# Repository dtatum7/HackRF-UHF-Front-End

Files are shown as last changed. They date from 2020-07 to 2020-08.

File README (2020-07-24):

Copyright 2020 Daniel H. Tatum

This source describes Open Hardware and is licensed under the CERN-OHL-P v2
You may redistribute and modify this documentation and make products
using it under the terms of the CERN-OHL-P v2 (https:/cern.ch/cern-ohl).
This documentation is distributed WITHOUT ANY EXPRESS OR IMPLIED
WARRANTY, INCLUDING OF MERCHANTABILITY, SATISFACTORY QUALITY
AND FITNESS FOR A PARTICULAR PURPOSE. Please see the CERN-OHL-P v2
for applicable conditions

https://github.com/dtatum7/HackRF-UHF-Front-End/blob/master/PCB_View.png

This project includes design and manufacturing files to produce a 400MHz to
500MHz UHF front end suitable for radio communications at distances of 5
miles or greater on a tuned omnidirectional antenna (as is used on a HAM
mobile rig, handy-talkie, or base station).

The project is in its infancy. HackRF UHF Front End is an evaluation and
prototyping platform to develop a half-duplex LNA and PA chain for the
HackRF at UHF frequencies covering HAM, commercial, GMRS, and other bands.
The design and layout files contain additional artwork to probe the RF
matching networks during testing. All power and control nets will be
externally controlled in the initial version. Futurerevisions will have
power supplies and control circuitry integrated onto the PCBA.

hardware notes:

Schematic, layout, and PCB manufacturing files were designed in KiCad, an open source electronic
design automation package. Simulations have been performed using LibreOffice
Spreadsheets and Qucs simulations as referenced in Documentation.

order of copper layers:
    Copper 1:  C1F (front)
    Copper 2:  C2
    Copper 3:  C3
    Copper 4:  C4B (back)

PCB description: 4 layer PCB 0.062 in
    Copper        1   0.5 oz foil plated to approximately 0.0017 in
    Dielectric  1-2   0.0119 in
    Copper        2   1 oz foil (0.0014 in)
    Dielectric  2-3   0.0280 in
    Copper        3   1 oz foil (0.0014 in)
    Dielectric  3-4   0.0119 in
    Copper        4   0.5 oz foil plated to approximately 0.0017 in

FR4 or similar substrate with Er=4.5 (+/- 0.1)
double side solder mask green
single side silkscreen white
6 mil min trace width and
6 mil min isolation

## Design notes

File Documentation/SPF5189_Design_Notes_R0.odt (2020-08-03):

SPF5189Z Design Notes

Daniel H. Tatum

Revision 0

08/02/20

# Introduction

The Qorvo SPF5189Z [1] meets frequency and gain requirements while delivering excellent linearity with an OIP3 of 39.5dBm. The output power of +22.5dBm at the 1dB compression point makes the amplifier an ideal driver for a 4W-8W power amplifier.Integration requires a +5V power supply at 90mA of current, band-limiting matching networks, and DC blocking capacitors at both the input and output terminals. The SOT-89-3 package is simple to install in a home lab with a board heater and quality soldering iron.

# Matching Network Design

Discrete matching networks are designed in the Quite Universal Circuit Simulator using manufacturer provided scattering parameter data and built-in microstrip models.

## Stability Circles

A check of the Rollett stability factor indicates that a stable match on both the input (red) and output (blue) networks can be made anywhere on the Smith Chart as in Figure 1.

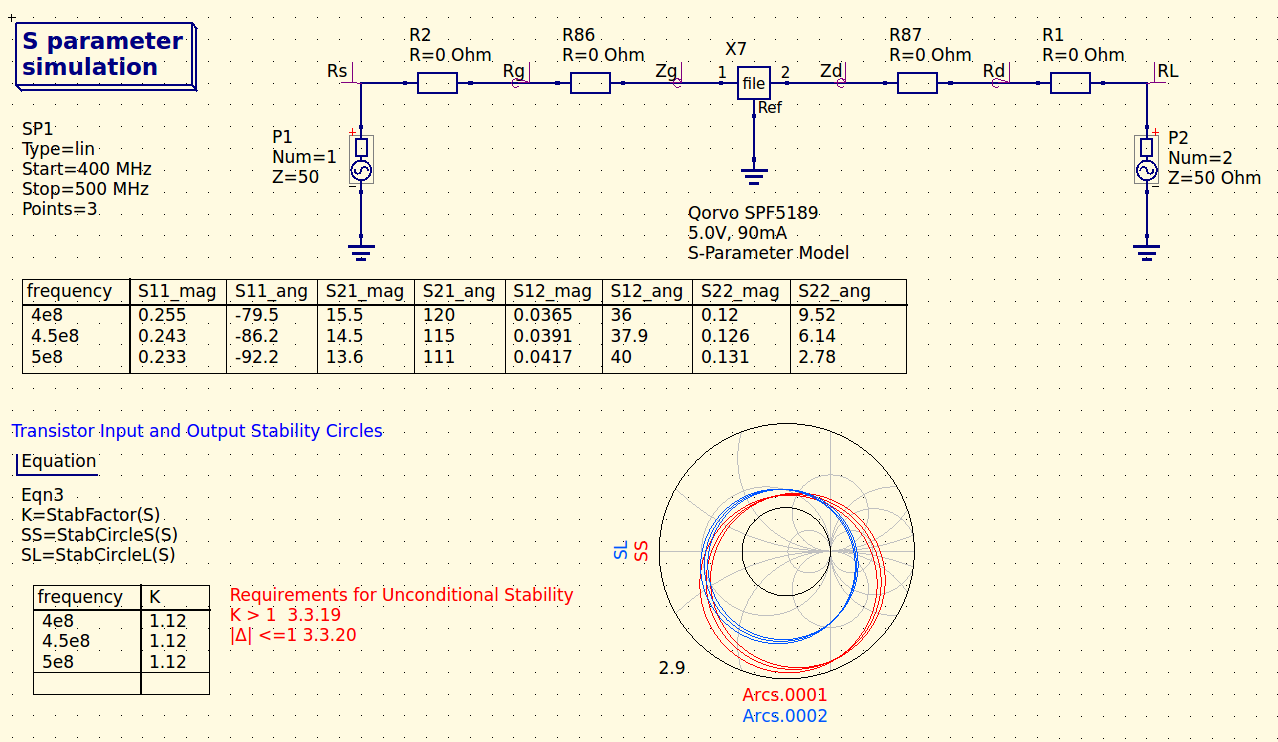
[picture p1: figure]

Figure 1. Qucs Simulation deck for Rollett stability factor.

## Input Network

A simulation has been configured in Qucs to automate the calculation of the required simultaneous conjugate matching coefficients to achieve maximum power output from the amplifier. The design process has been borrowed from [2] with the resulting coefficients in Figure 2.

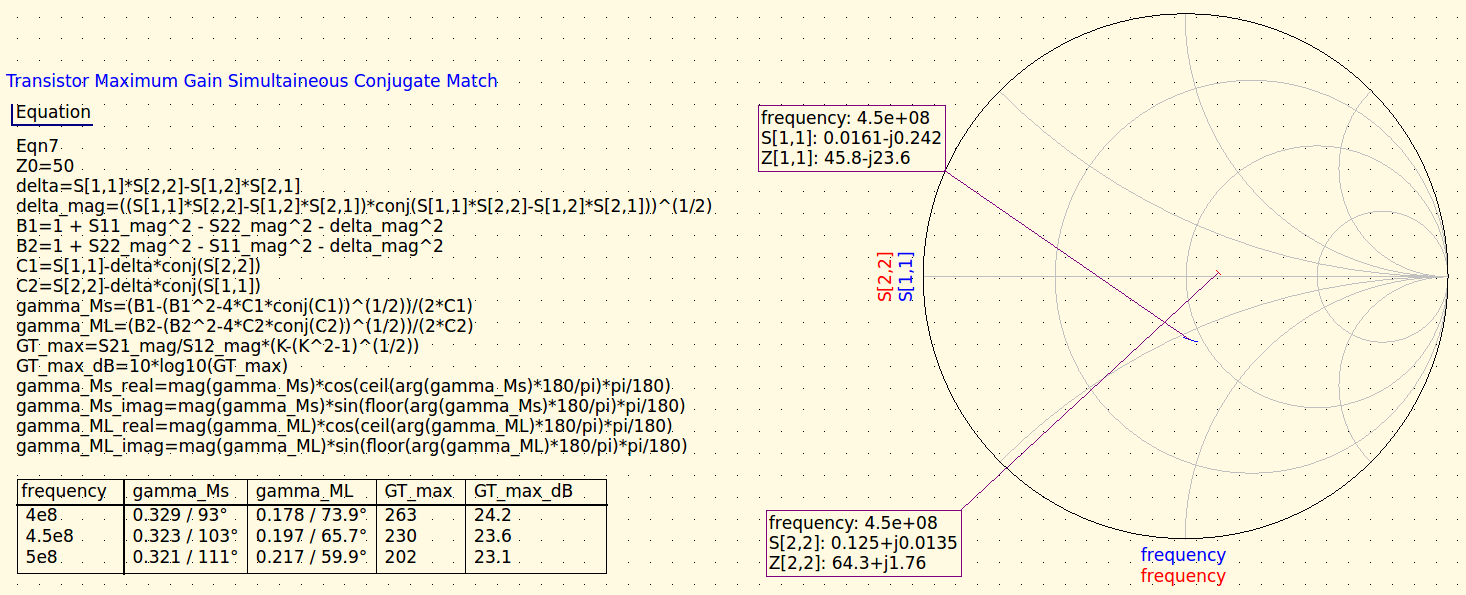
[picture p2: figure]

Figure 2. Simultaneous conjugate matching reflection coefficients for the source (gamma_Ms) and load (gamma_ML) ports calculated using S-parameter data. The input reflection coefficient, S[1,1] (blue), and output reflection coefficient, S[2,2] (red), presented on the Smith chart represent the the reflection coefficients seen by the ports with characteristic impedance of 50Ω.

The required input impedance is then calculated and presented rectangular form in Figure 2 to subsequently determine required component values.

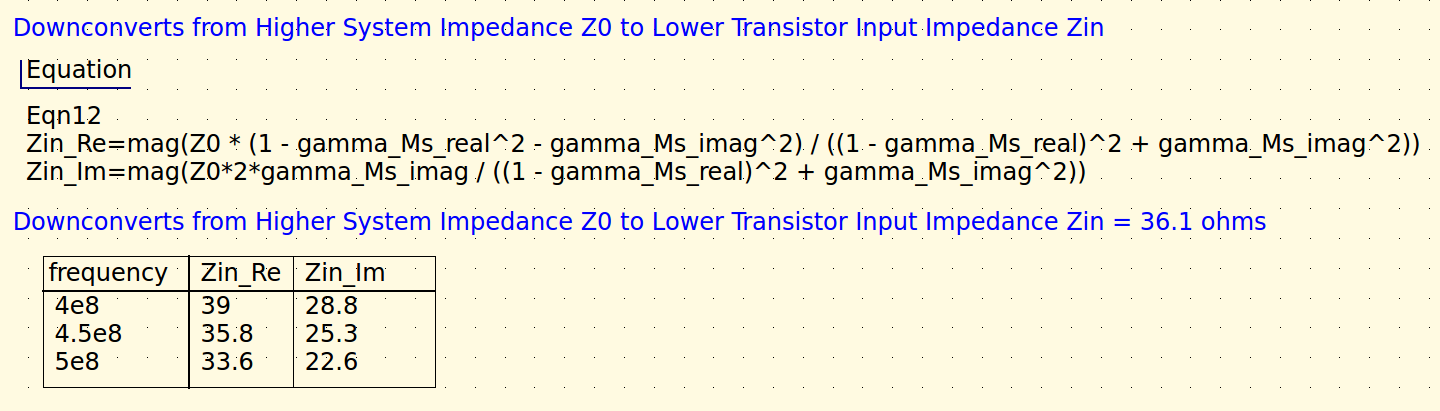
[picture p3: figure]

Figure 3. Transistor input impedance calculation in Qucs for simultaneous conjugate match. The mag() operator is used to reduce complex floating point numeric error in the result.

The input network topology is a 2nd order Chebyshev bandpass matching network which converts from the system characteristic impedance to the lower gate input impedance while simultaneously band limiting the input signal.

## Output Network

The output network is a 3rd order Chebyshev bandpass matching network with converts from the drain output impedance to the lower system characteristic impedance.

References

[1] Qorvo, Inc., SPF5189Z, https://www.qorvo.com/products/p/SPF5189Z

[2] G. Gonzalez, Microwave Transistor Amplfiers, 1997

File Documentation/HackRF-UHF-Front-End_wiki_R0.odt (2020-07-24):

HackRF UHF Front End

  Description
  This project includes design and manufacturing files to produce a 400MHz to 500MHz UHF front end suitable for radio communications at distances of 5 miles or greater on a tuned omnidirectional antenna (as is used on a HAM mobile rig, handy-talkie, or base station).
  The project is in its infancy. HackRF UHF Front End is an evaluation and prototyping platform to develop a half-duplex LNA and PA chain for the HackRF at UHF frequencies covering HAM, commercial, GMRS, and other bands. The design and layout files contain additional artwork to probe the RF matching networks during testing. All power and control nets will be externally controlled in the initial version. Future revisions will have power supplies and control circuitry integrated onto the PCBA.
  Table of Contents
- Documentation
  - Hardware Description
    - System Diagram / Chain Lineup
    - Schematic and Layout Simulation
  - Bring-up and Testing
  - Operation
- Simulations: Archive of LibreOffice Spreadsheets and Qucs simulations referenced in Documentation.
- Hardware: Archive of Kicad project files referenced in Documentation.
- Fabrication: Archive of manufacturing files referenced in Documentation.
- Software: Archive of software referenced in Documentation.
- Mechanical: Archive of mechanical designs referenced in Documentation.
  License

Copyright 2020 Daniel H. Tatum

This source describes Open Hardware and is licensed under the CERN-OHL-P v2 You may redistribute and modify this documentation and make products using it under the terms of the CERN-OHL-P v2 (https:/cern.ch/cern-ohl). This documentation is distributed WITHOUT ANY EXPRESS OR IMPLIED WARRANTY, INCLUDING OF MERCHANTABILITY, SATISFACTORY QUALITY AND FITNESS FOR A PARTICULAR PURPOSE. Please see the CERN-OHL-P v2

for applicable conditions

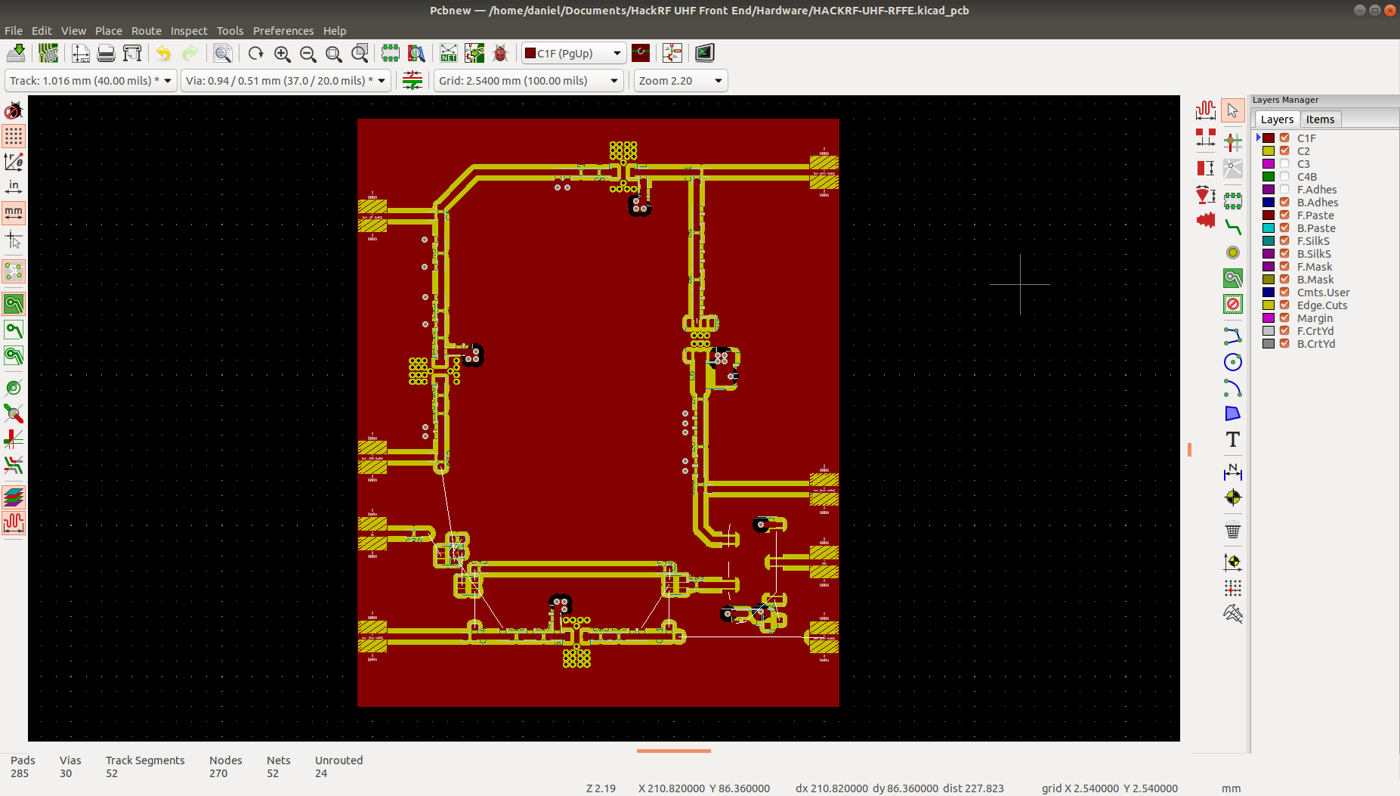
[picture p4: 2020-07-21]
PCB_View.png

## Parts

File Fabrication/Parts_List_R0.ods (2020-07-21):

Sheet: Test Equipment
Item | Description | MPN | Quantity | Price | Extended | Tax | Shipping | Total | Web Link
1 | RF Power Meter |  | 1 | $79.00 | $79.00 |  |  |  | https://www.immersionrc.com/fpv-products/rfpwrv2/
2 | Adapter, SMA(F) to SMA(F) |  | 5
3 | Adapter, SMA(M) to SMA(M) |  | 5
4 | Coaxial Cable, SMA(M) to SMA(M), 0.85” diameter, 3” length |  | 5
5

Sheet: Semiconductors and Discretes
Item | Description | MPN | Quantity | Price | Extended | Tax | Shipping | Total | Web Link
1 | TRX Relay | 1462051-2 | 1 | $12.24 | $12.24 |  |  |  | https://www.mouser.com/ProductDetail/TE-Connectivity-PB/HF3-53?qs=LU7oW20kJpORGl8sXo9z6Q%3D%3D
2 | Amplifier #3 | AFT05MS031NR1 | 1 | $11.84 | $11.84 |  |  |  | https://www.mouser.com/ProductDetail/NXP/AFT05MS031NR1/?qs=Xt8Ff6slEhtpCpo7lHpXHg%3D%3D
3 | Amplifier #2 | AFT05MS003N | 1 | $2.72 | $2.72 |  |  |  | https://www.mouser.com/ProductDetail/NXP-Semiconductors/AFT05MS003NT1?qs=xufs61hA5MYrGMTt5a7DOw%3D%3D
4 | Amplifier #1, LNAs | BGU6104 | 10 | $0.646 | $6.46

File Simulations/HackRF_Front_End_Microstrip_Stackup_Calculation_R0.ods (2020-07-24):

Dimension | Quantity |  | Comment
W [mil] | 25.6 |  | Trace width chosen based on compatibility with component footprints and spacing
h [mil] | 13.4 |  | Substrate height chosen to result in 50 ohm characteristic impedance given the trace width above
W [m] | 0.000650 |  | 40 mil trace → [m]
h [m] | 0.000340 |  | 62 mil / 3 ~ 20 mil → [m]
W/h [] | 1.91 |  | W/h >= 1 must be true for eqs. 2.5.5 and 2.5.7 below to be valid
er [] | 4.45 |  | Dielectric constant of FR4
eff [] | 3.36 |  | Effective dielectric constant of FR4 with air above for microstrip transmission lines based on W, h, and er above (Gonzalez p.144 eq. 2.5.7)
Z0 [Ω] | 50.00 |  | Microstrip transmission line impedance based on W, h, and er above (Gonzalez p.144 eq. 2.5.6)
f0 [Hz] | 500E+06
λ0 [m] | 0.600
λ [m] | 0.327
λ [mm] | 327
[mm/deg] | 0.910
1 deg [mm] | 0.91 | 0.036 | 0.016 inches for 1100 MHz
2 deg [mm] | 1.82 | 0.072 | 0.032inches for 1100 MHz
5 deg [mm] | 4.55 | 0.179 | 0.081 inches for 1100 MHz
10 deg [mm] | 9.10 | 0.358
45 deg [mm] | 40.93 | 1.611
90 deg [mm] | 81.86 | 3.223 | 3.418 inches for 470 MHz
180 deg [mm] | 163.73 | 6.446
360 deg [mm] | 327.45 | 12.892

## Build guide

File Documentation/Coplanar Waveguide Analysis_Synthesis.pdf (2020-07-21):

7/3/2020 | Coplanar Waveguide Analysis/Synthesis

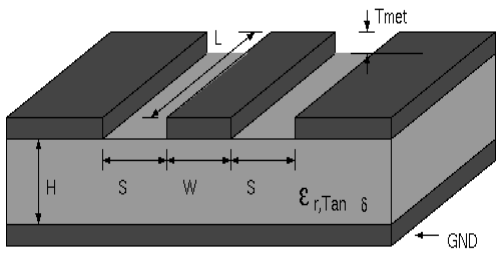
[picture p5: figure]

wcalc.sourceforge.net/cgi-bin/coplanar.cgi?wc_unit_menu_1_0=nH&wc_unit_menu_1_1=inch&wc_unit_menu_2_0=mOhm&wc_unit_… 1/1

# Coplanar Waveguide Analysis/Synthesis Calculator

Values In Sync
Ls = | 7.59382 | nH | / inch
Rs = | 105.851 | mOhm | / inch
Cs = | 3.18333 | pF | / inch
Gs = | 239.681 | uMho | / inch
Z0 = | 48.8415 + j 0 [ohm]
Loss = | 0.0237216 | dB
Loss/len = | 0.0602529 | dB | / inch
Skin depth = | 0.115538 | mil
Delay = | 0.0612121 | ns
End correction = 0 | inch
Corrected length = 10 | mm

### Metal width

(W) | 1 | mm | calc

### Metal

spacing (S) | 0.9 | mm | calc

### Trace length

(L) | 10 | mm

### Metal

thickness (Tmet) | 0.035 | mm

### Metal resistivity (RHO) (http://wcalc.sourceforge.net/resistivity.html)

1.7e-08 | Ohm | - m

### Metal surface roughness (RGH)

0.001 | mil | -rms

### Substrate

thickness (H) 0.5 | mm | calc

### Substrate

relative dielectric constant (Er) (http://wcalc.sourceforge.net/permitivity.html) | 4.45 | | calc

### Substrate loss

tangent (tand) (http://wcalc.sourceforge.net/permitivity.html) | 0.02
Frequency | 500 | MHz
Analyze Reset | | Include bottom side ground

### Characteristic

Impedance | 48.8415 | [ohms]

### Electrical

Length | 11.0182 | [degrees]

### Return to the main CGI-Wcalc Page. (http://wcalc.sourceforge.net/cgi-wcalc.html)

$Id: footer.html,v 1.9 2009/01/11 05:37:45 dan Exp $
$Id: coplanar.html,v 1.6 2009/02/11 00:00:28 dan Exp $ Copyright © 2001-2009 Dan McMahill. ALL RIGHTS RESERVED. mcmahill at alumD0TmitD0Tedu

### CREDITS

This CGI program makes use of the CGIC library which carries the following copyright.

CGIC, copyright 1996, 1997, 1998, 1999, 2000 by Thomas Boutell and Boutell.Com, Inc.. Permission is granted to use CGIC in any application, commercial or noncommercial, at no cost. HOWEVER, this copyright paragraph must appear on a "credits" page accessible in the public online and offline documentation of the program. Modified versions of the CGIC library should not be distributed without the attachment of a clear statement regarding the author of the modifications, and this notice may in no case be removed. Modifications may also be submitted to the author for inclusion in the main CGIC distribution.

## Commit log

2020-07-21 HackRF UHF Front End Initial Commit
    [Amp_1.sch, Amp_2.sch, HACKRF-UHF-RFFE.kicad_pcb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]
2020-07-24 Added discrete Chebyshev input filter to schematic based on Qucs simulationd. Artwork not done. It has occurred to me that I need to do some major cleanup of the test points on this PCBA.
    [Chebyshev_Input_BPF_R0.sch, HACKRF-UHF-RFFE.kicad_pcb, HACKRF-UHF-RFFE.sch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]
2020-07-24 Major cleanup to both the schematic and directory structure. Stackup has changed accomodate to 0.65mm trace width. Chebyshev filter lived through the experience in the Qucs simulation; others not che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
    [ADG904.sch, Chebyshev_Input_BPF_R0.sch, Chebyshev_Input_BPF_R1.sch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]
2020-08-03 Improving LNA simulations and Documentation package. More to come on this one.
    [Chebyshev_Input_BPF_R0.sch, HACKRF-UHF-RFFE.kicad_pcb, HACKRF-UHF-RFFE.sch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]
2020-08-03 Working on LNA design documentation package. Much will be added. Schedule pressure from a job interview at a killer company where I'd actuall be employed and paid to to this kind of stuff is going to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
